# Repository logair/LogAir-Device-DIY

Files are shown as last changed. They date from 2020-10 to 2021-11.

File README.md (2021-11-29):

# Hardware docs for the DIY LogAir device

- Schematics
- PCB
- BoM
- Arduino code

The hardware as it is streams, once per second, the following data through BLE and to the uSD card:
Latitude, Longitude, Altitude, Speed, Heading, Temperature, Relative Humidity, Atmospheric Pressure, PM1, PM2.5, PM4, PM10

The Arduino-compatible MCU is a Bluepill, a generic implementation of the STM32F103. The chip is flashed with a code compiled with the Arduino IDE and the following libraries: NeoGPS, PMS Library, BME280, SdFat.

The data transmissio nprotocol is extensible to allow implementation of different sensors.

# How To

## Assemble
<details>
  <summary>Click to expand for instructions!</summary>
  
  ### Material

- LogAir PCB
- Bluepill + connectors
- BME280 + connector
- uSD module
- BLE module
- PMS7003 + connector
- DC step-up
- Charger module
- GPS module

- Soldering iron + tin
- double-sided tape + jelly tape if available
- cutting pliers
- flat pliers
  
  ### Instructions

0. A very first step should be to try and upload code to the Bluepill. This is before the rest as it happened that the chips could not be programmed, and realizing that after all that work is not ideal. Upload a bootloader, a blink code, and there you go.

1. Solder the Bluepill connectors. Use the holes in the PCB as a guide for alignment. The G (GND, ground) pins are harder to solder, because of the copper mass involved.
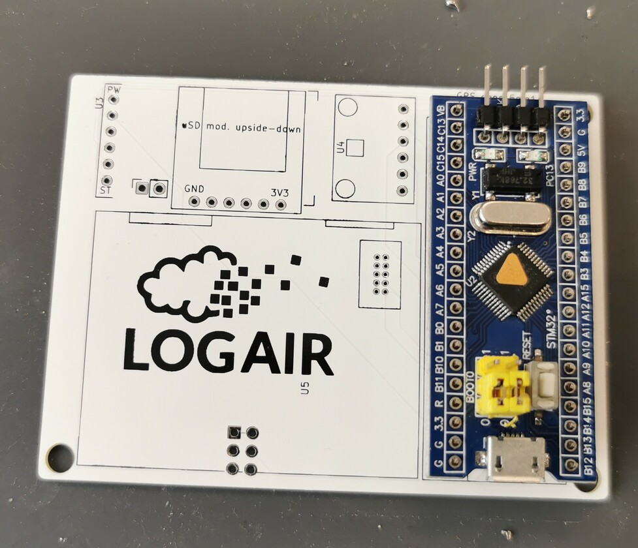
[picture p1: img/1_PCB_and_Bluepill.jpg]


2. Solder the assembled Bluepill to the PCB. Pay attention to the orientation.
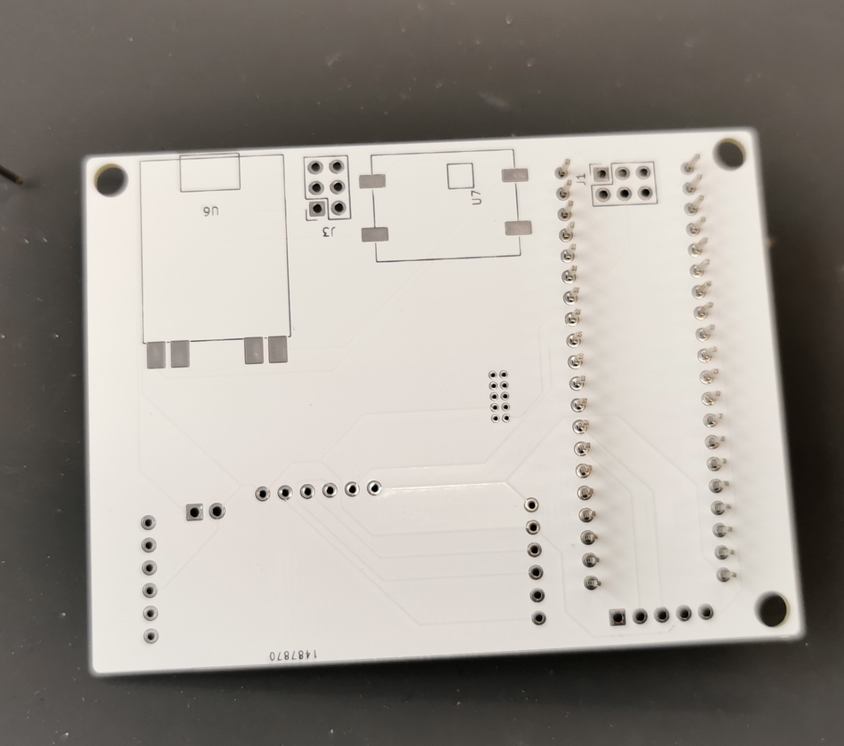
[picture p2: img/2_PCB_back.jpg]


3. Prepare the BME280 (solder the connectors), the BLE module (straighten the pins with a flat plier), and the uSD module
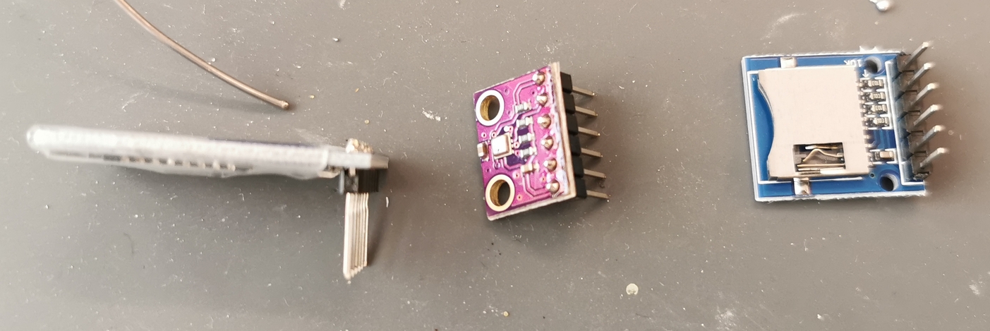
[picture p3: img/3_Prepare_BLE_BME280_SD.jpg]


4. Place the BLE, BME, and uSD modules. Follow the picture, the BME280 (violet module) should be as far as possible from the PCB), with its pins barely sticking through on the other side.
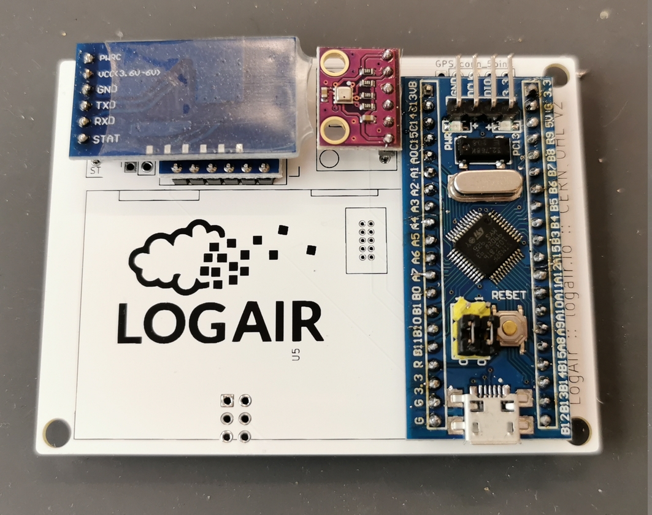
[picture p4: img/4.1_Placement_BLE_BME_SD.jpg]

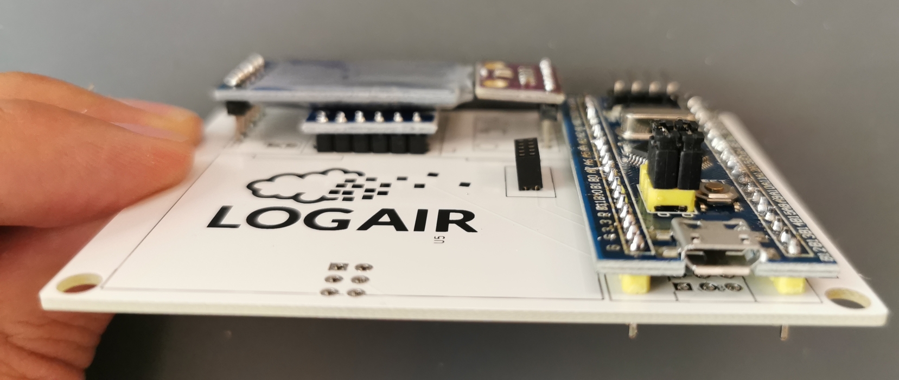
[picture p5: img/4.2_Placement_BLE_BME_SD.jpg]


5. Prepare the PCB for the power modules: put a thin layer of tin on the (blue) charger module pads, and a solder blob on one of the (red) step-up pads
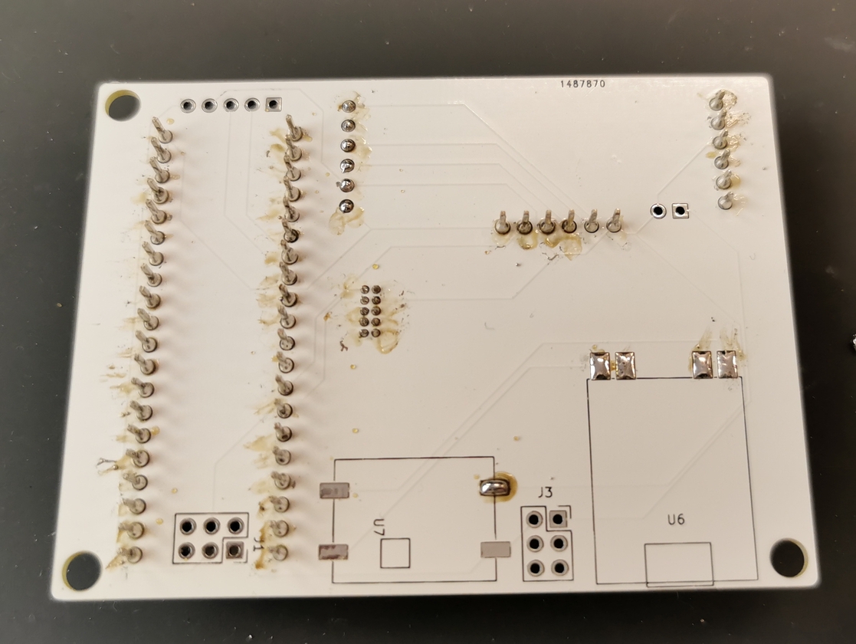
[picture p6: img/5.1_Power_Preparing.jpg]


6. Solder the charger module by putting it in place, and adding solder on the pads from the top. I count about 5 seconds of applying heat for the tin applied on step 5 to melt. Then solder the step-up module using the first pad to hold it in place. When you are done, check the conductivity between the pins of the two modules, and that between the pads of the charging module. The latter because the method used to solder can produce 'tin overflows'. 
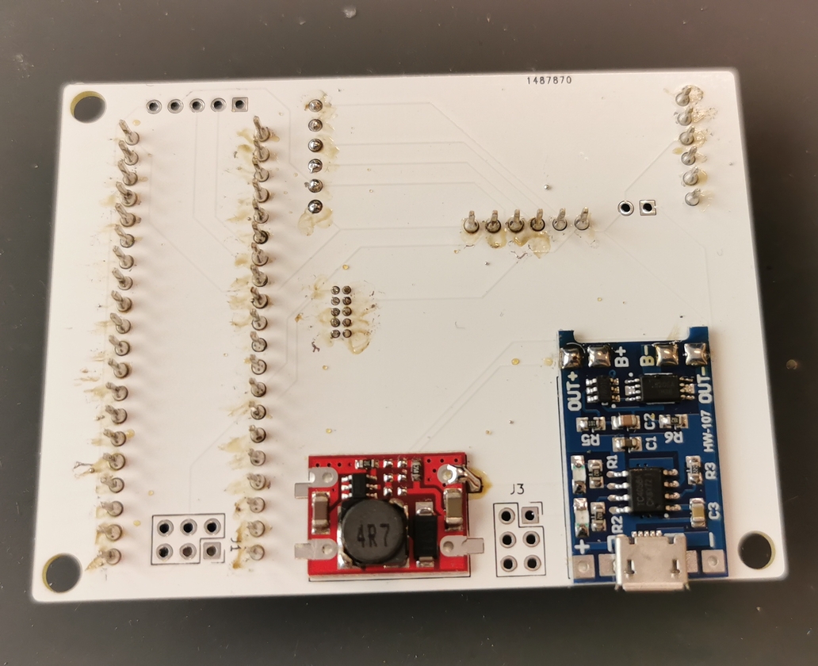
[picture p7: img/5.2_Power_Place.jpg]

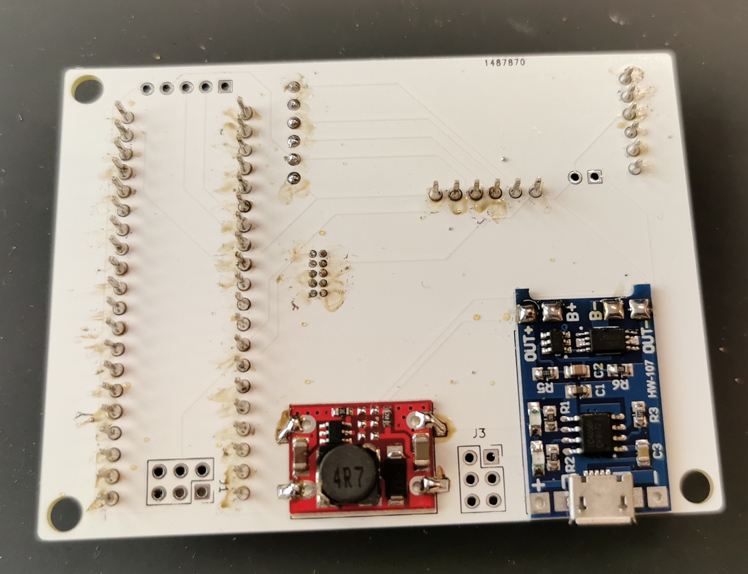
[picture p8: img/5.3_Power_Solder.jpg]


Then place and solder the switch. Here, try to apply a minimal amount of tin. As the other side of the pins will go against the PMS7003 which has a conductive casing, the pins should be cut or filed down, then taped over (two layers of normal, clear tape are enough)
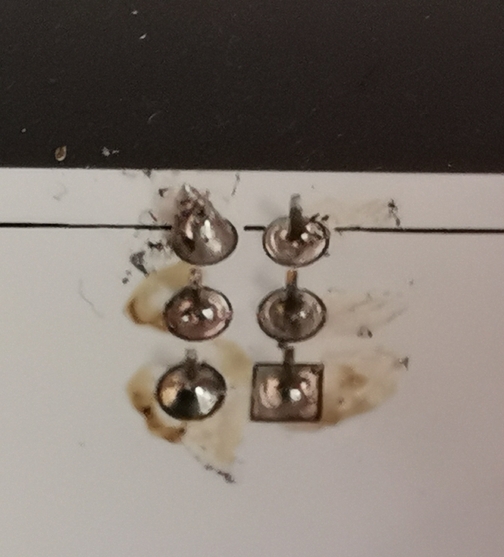
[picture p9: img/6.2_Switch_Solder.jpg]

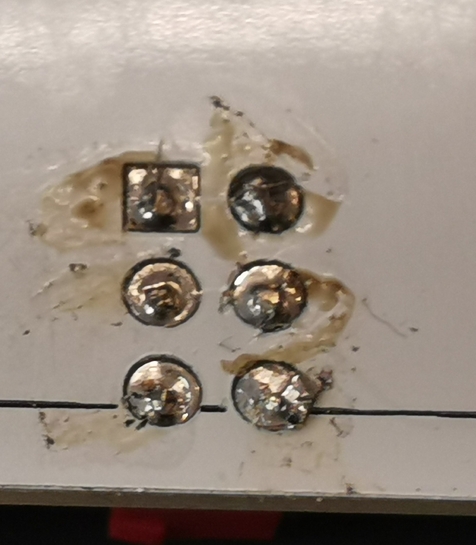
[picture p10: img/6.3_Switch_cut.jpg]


7. Bend lightly the SWD pins of the Bluepill to give room for soldering the GPS wires
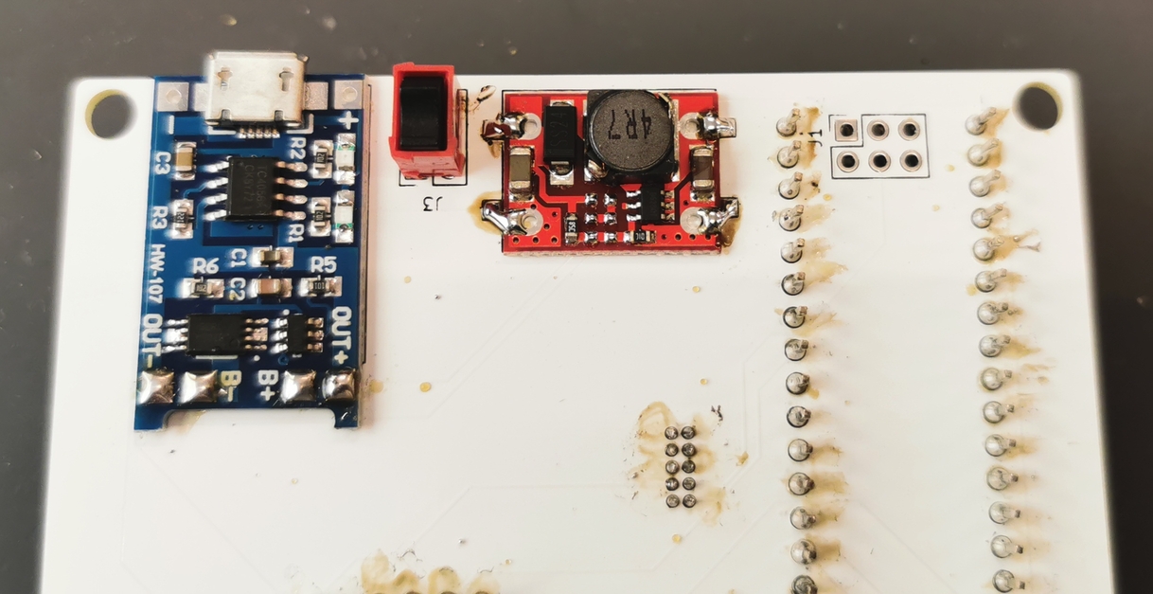
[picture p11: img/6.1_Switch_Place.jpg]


8. Solder the GPS wires. The order is the same as their order on the GPS-side plug, you can use the PCB markings (5V is red) and pictures to help you. The wires should not go over each other at any point for the order to be preserved.
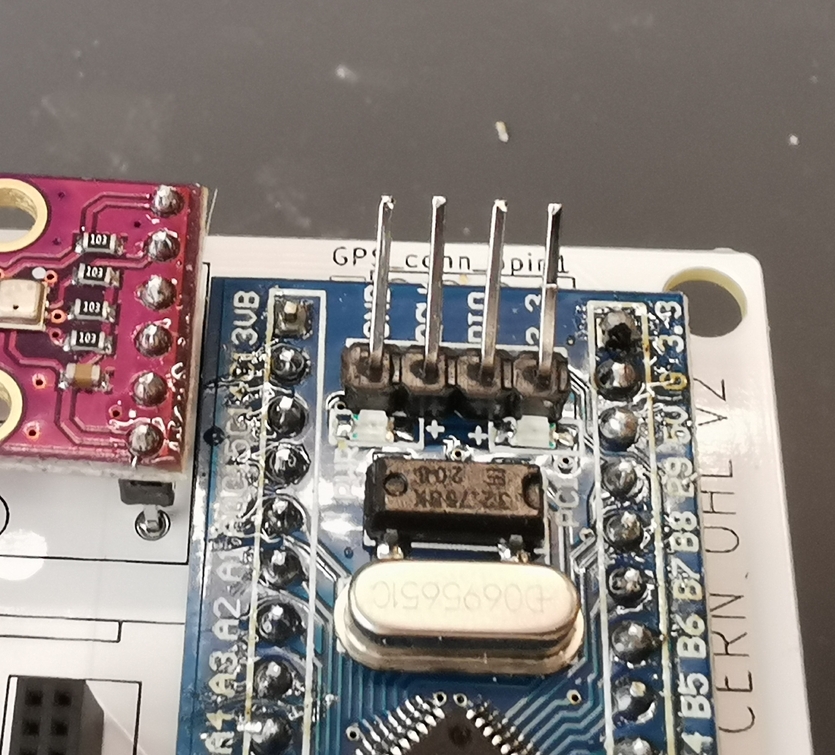
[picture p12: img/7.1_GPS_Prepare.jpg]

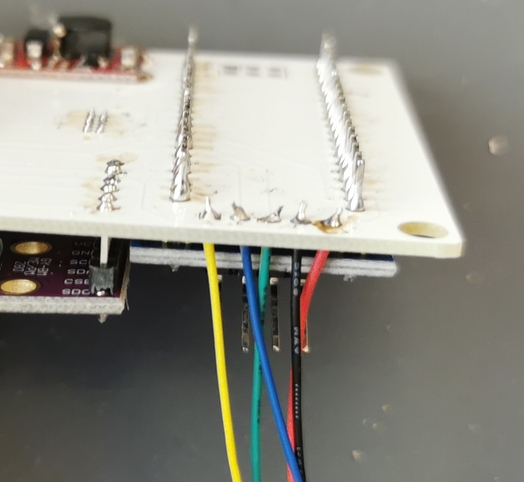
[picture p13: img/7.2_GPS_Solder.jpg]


9. Solder the connector for the PMS7003. As the width of the Bluepill vary a bit, it is safer to solder it lightly 'bent' away from the bluepill. To do that, solder the pins that are on the far side from the Bluepill first, then plug the PMS7003 in to see how thing fit. Then remove and solder the rest. 5-10 degrees should do.
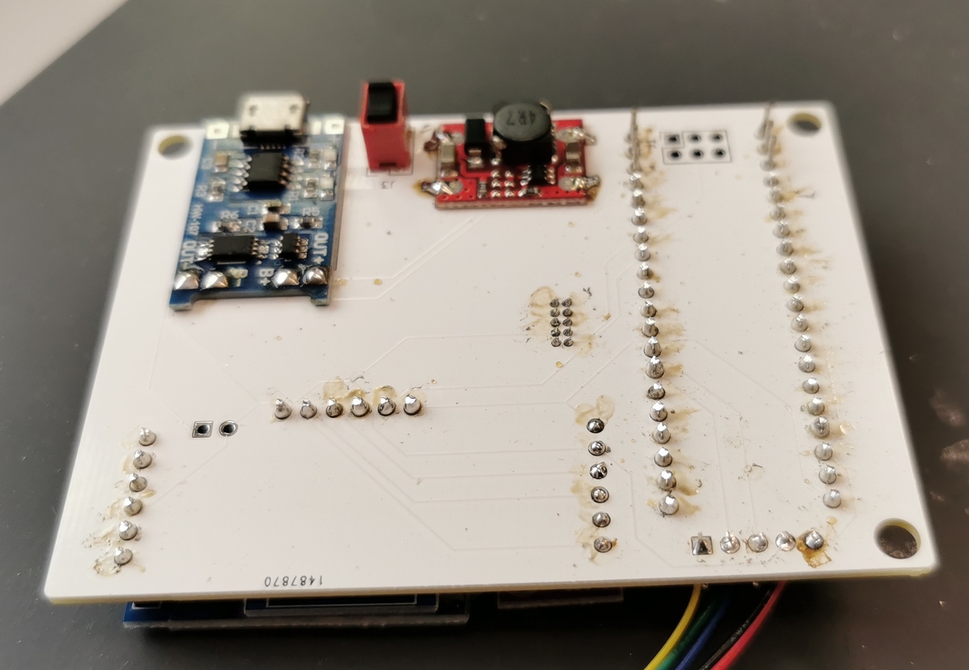
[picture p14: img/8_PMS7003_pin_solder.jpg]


10. For a smaller device, I cut most of the pins apparent on the back of the PCB to the top of the tin cone. Apply insulation on the pins, and this is important. I use a sticky, translucent, think tape I found on aliexpress. Any other ~1-2mm insulating material will easily do.
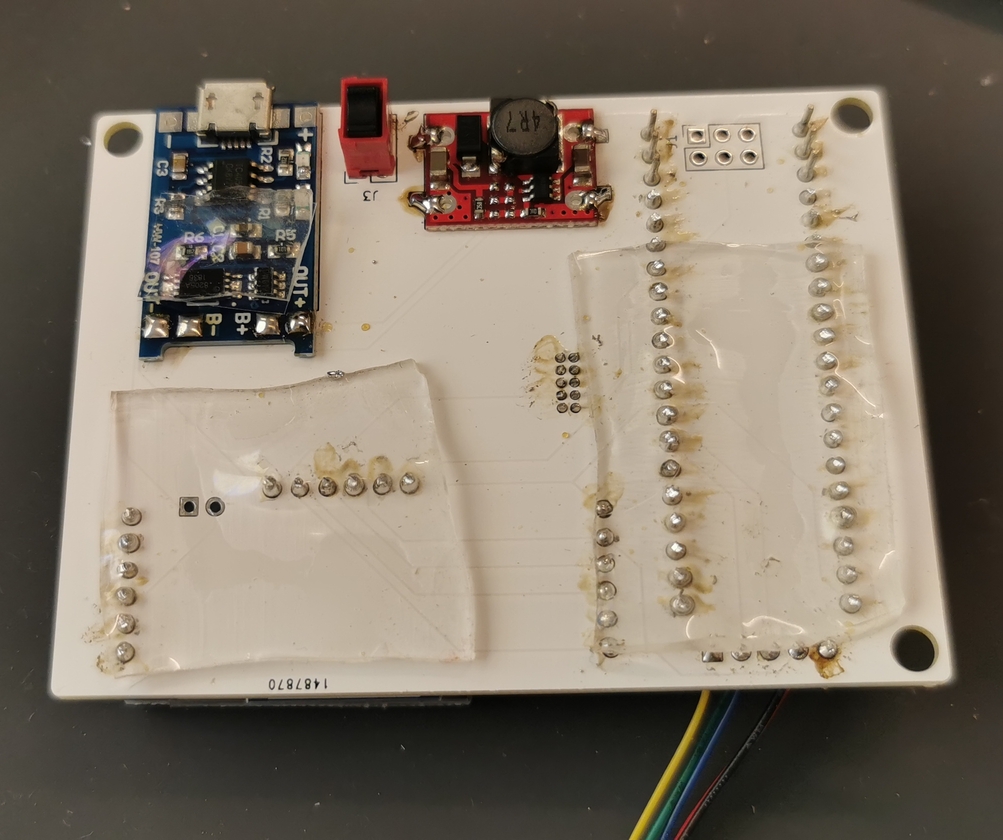
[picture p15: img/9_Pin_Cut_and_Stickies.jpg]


11. Solder the battery wires to the charger module pads
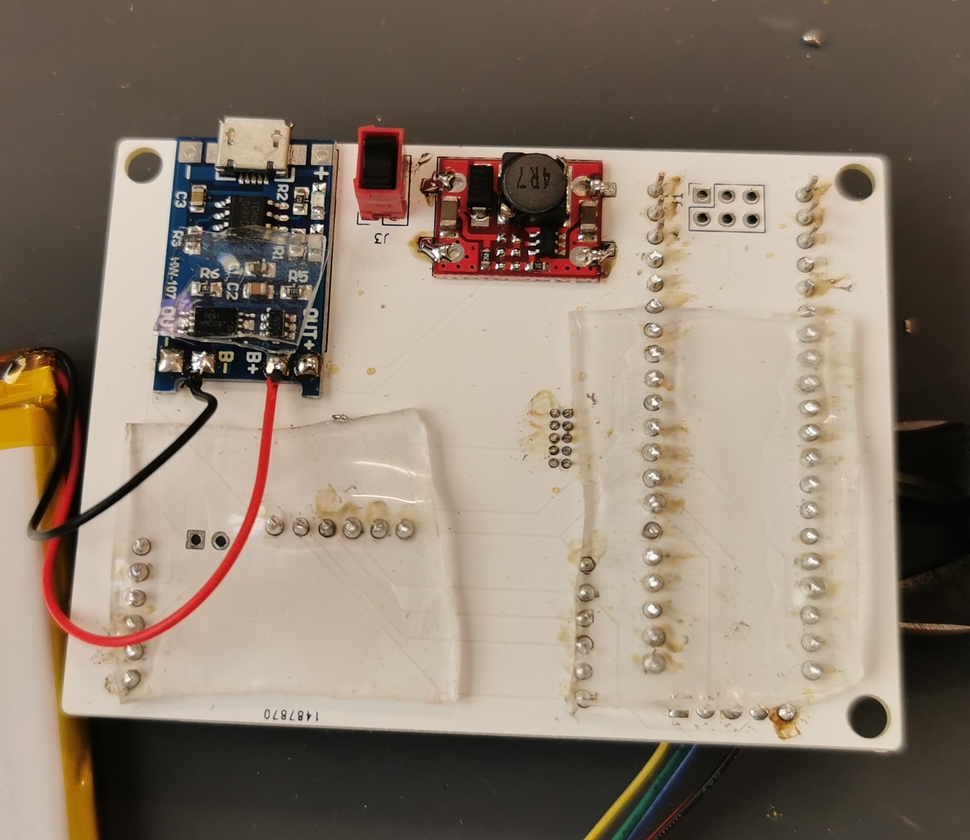
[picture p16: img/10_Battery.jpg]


12. Before finalizing the assembly, write down the PMS7003 serial number somewhere, to track device quality :)
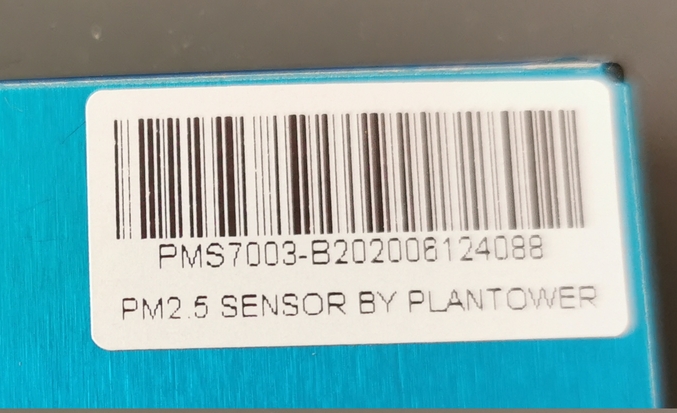
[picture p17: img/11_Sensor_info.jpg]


13. And it is done :)
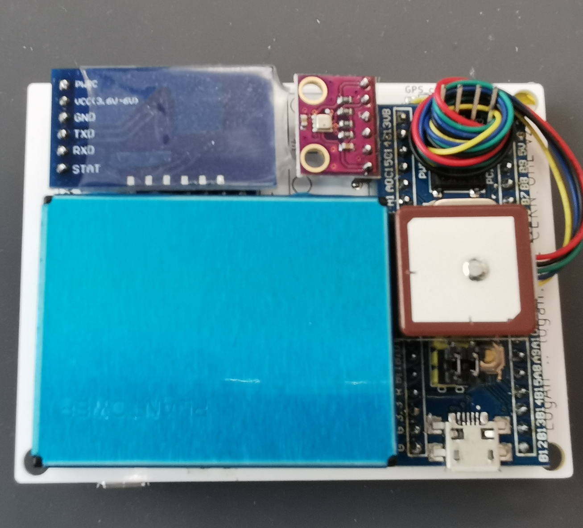
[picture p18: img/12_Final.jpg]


  </details>
  
## Program

<details>
  <summary>Click to expand for programming instructions!</summary>
  
### Pre-requisites
- A Bluepill with functional bootload (e.g. generic_boot20_pc13.bin from https://github.com/rogerclarkmelbourne/STM32duino-bootloader
- Install Arduino IDE
- Install board definition:File > Preferences > Additional Boards Manager URLs: add the following URL to the list (empty by default):
  `https://github.com/stm32duino/BoardManagerFiles/raw/main/package_stmicroelectronics_index.json`
- Tools > Board > Boards Manager > Search 'STM32' > Install 'STM32 MCU based boards'
    
<details>
<summary>For older instructions using unofficial stm32duino core</summary>
  
- Install board definition:File > Preferences > Additional Boards Manager URLs: add the following URL to the list (empty by default):
`http://dan.drown.org/stm32duino/package_STM32duino_index.json`
- Tools > Board > Boards Manager > Search 'STM32' > Install 'STM32F1xx/GD32F1xx boards'
- Once done, close the Board Manager and Select the Board: Tools > Board > STM32F1 Boards (Arduino_STM32) > Maple mini
  
NO NEED TO FOLLOW THE CONFIGURE SECTION BELOW.
    
</details>
  
### Configure
  - Select the proper board:
  `Tools > Boards > STM32 Boards (selected from submenu) > Generic STM32F1 series`
  - Enable configurations we need:
    - `Tools > U(S)ART Support > Enabled (Generic 'Serial')`
    - `Tools > USB Support > CDC (Generic Serial supersedes U(S)ART)`
    - `Tools > Upload Method > Maple DFU Bootloader 2.0`

### Libraries
Install the following libraries from the Library Manager
Tools > Manage Libraries... 

- NeoGPS: Install, and replace the contents of `$HOME/Arduino/libraries/NeoGPS/src/GPSport.h` by:
```
#ifndef GPSport_h
#define GPSport_h

#define gpsPort Serial2
#define GPS_PORT_NAME "Serial2"
#define DEBUG_PORT Serial

#endif
```
- BME280 by Tyler Glenn
- PMS Library by Mariusz Kacki
  
## Connect, compile and upload
Let us now try and upload a quick code to test if all works...

- Open the Blink example, and add `#define LED_BUILTIN PC13` at the very beginning
- Select the Port: Tools > Port > ... (depends on your OS)
- Press the Compile and Upload arrow....

If the upload does not go through, this might be because the board cannot auto-reset with your computer.
To upload, you will need to manually reset by pressing the button you can see near where the GPS chip is stuck just before pressing the Compile arrow. It takes a bit of trial and error and some OS's need it while some others don't.

## Upload the LogAir code
Download the code from the repository, and follow the same process as above.

## Connect
UART parameters to connect to the serial monitor are the ones set in the code. The default is 112500, but 9600 was previously used.

## Troubleshoot

### Board appears in dmesg, but not in lsusb 
You might need to create a udev rules file
`/etc/udev/rules.d/45-bluepill.rules`
```
ATTRS{idVendor}=="1eaf", ATTRS{idProduct}=="0004", MODE="0666" SYMLINK+="maple", ENV{ID_MM_DEVICE_IGNORE}="1"
ATTRS{idVendor}=="1eaf", ATTRS{idProduct}=="0003", MODE="0666" SYMLINK+="maple", ENV{ID_MM_DEVICE_IGNORE}="1"
```
  </details>
  
## Use

<details>
  <summary>Click to expand for usage instructions!</summary>
  
### Turning ON / OFF
The switch onthe back of the device allows to turn the device on and off.

The red or green blinking light shows when the device is writing on the SD card. When the LED is ON, the device should not be turned OFF as it might corrupt the card.

### Blinking LEDs

The modules we use include LEDs of varying colors. Here are some useful informations you can get from them:

- Bluetooth LED (green or red), left side of the device: This LED is blinking if no phone is connected to the device, and stays on when a connection is active.
- GPS LED (blue and red):
  - The red LED shows the module is powered, and should always be on when the device runs. 
  - The blue LED is blinking when the module receives signals strong enough to get a 'fix', or know its position. This is important if you rely on the SD card only to record the measurements, i.e. if you're not using a smartphone to send your data to the server.
- Device LEDs:
  - Left LED: red or green, signals the controller receives power. Should always be ON when the device is turned on.
  - Right LED: red or green, currently parametered to signal the device is writing to the SD card and should not be powered off. You can turn the device OFF when the LED is OFF.

### With the LogAir APP
Follow the instructions on our video tutorial.

### Stand-alone
The LogAir device records its measurements on the micro-SD card, which can be extracted and imported into a spreadsheet or GIS program.

The limitation in this mode is that the device can only rely on its own GPS module for time and position. This means that, before a valid GPS signal is acquired, the measurements on the SD card will not list any time or position. 

The signal depends on your location, the time of the day, if there are obstacles between the device and the sky, etc. Indoor measurements are often difficult, but windowsills sometimes give good results.

We are trying to find a way to give the current time to the device by using a program on the computer, or preparing it on the SD card, but there is no easy solution there... See ToDos, input welcome :)

</details>

# ToDo

Here are several items that are planned, currently developed, or on hold pending contributions. If you are interested in any of them be it for giving a helping hand or advices, please get in touch :)
  
## Hardware

These items focus on the device conception, including electronics, casing, production, etc.

<details>
  <summary>Click to expand for Hardware development tasks!</summary>
  
- Disconnect PC14 and PC15 for RTC reliability
- Better power supply, as this one just charges and discharges blindly.
- Integrate the components on a printed circuit board
- Replace the BLE module with an ESP32 (the STM32 might have to stay, as ESP32 are more limited, e.g., available UARTs)
- Make a similar MVP with SPS30 & SHT3x
- Add a LoRa chip! See Clement's work
- ...

</details>

## Firmware

Firmware development focuses on the program that makes the device run. The brain within the machine :)

<details>
  <summary>Click to expand for Firmware development tasks!</summary>

- Provide a time base when no GPS signal is present, and no phone is connected
  - Implement RTC (there is an on-board crystal on the Bluepill).
  - Implement time input from serial (BLE and/or PC)
- Implement better data storage and upload 
  - Log data with human-readable time as well as UNIX timestamp
  - Revamp buffering to limit uSD write operations
  - Revamp data storage on the SD card (textfile + DB?)
  - Implement deferred data upload for when uplink not continuously available
- Implement online GPS config: some changes to the embedded GPS FW are sometimes necessary for best operation
  - Get and store almanach/ephemeris on uSD card! This would really help with no-phone collection
  - Other generic config, constellations, accuracy requirements, etc.
- Implement component recognition: find out which sensors are used from their output stream (starting with PM sensor)
- Add interrupts everywhere?
- ...

</details>

## APP

Here, developmetn of our application that helps collect and send data from the device to the servers, and get it back in forms of maps, messages, etc. Our UI sucks? Contribute a better one ;)

<details>
  <summary>Click to expand for APP development tasks!</summary>
  
- All 
  - Implement API key for upload/download

- Android version
  - APP should check at startup that GPS is enabled (and available in background if knowable) and prompt if not. 
  - Make it simpler: no settings, sending all packets stored every 10sec, etc
  - Auto-connect: priority to previously connected devices, then to '.*logair.*', etc
  - Map should be loaded at startup, not only when map tab is opened
  - ...

- iOS version
  - Make one :x Nicos is on it!
  - ...

</details>

## Backend

All the work that helps gather the data, safekeep it, develop ways to use it, share it, etc. DBs, services, APIs and the like. Put your hoodie on and hack away!

<details>
  <summary>Click to expand for Backend development tasks!</summary>
  
  - Implement API key for upload/download
  - ...

</details>

## Data

All the work that develop ways to analyse, understand and use the data. Algorithms, GIS, dashboards etc.

 <details>
  <summary>Click to expand for Data visualisation and Data science tasks!</summary>
  
  - Make a dashboard! 
  - Build a QGIS server that works fast enough
  - Find missing data points in the contributions, and signal them for collection
  - Find periods in the signal, and exploit them
  - Build a better pipeline for extraction and analysis

</details>

# Upcoming

- Arduino library configs
- ToDo list updates
- Assembly instructions (video?)

Licensed under [CERN OHL v.1.2 or later](https://ohwr.org/project/cernohl/wikis/home)

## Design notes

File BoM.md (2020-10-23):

|Part | Cost (USD)  | Data Sheet |
|---|---|---|
|PMS 7003  |$13.00 |http://www.aqmd.gov/docs/default-source/aq-spec/resources-page/plantower-pms5003-manual_v2-3.pdf|
|BME280 SPI |$3.00 |https://cdn-shop.adafruit.com/datasheets/BST-BME280_DS001-10.pdf |
|GG1802 gps |$10.00 |http://www.stotoncn.com/gnssmodule/showproduct.php?lang=en&id=63 |
|HM-10 compatible bluetooth |$4.00 | https://www.iot-experiments.com/jdy-08/ |
|Bluepill |$2.00 |https://www.techshopbd.com/uploads/product_document/STM32bluepillarduinoguide(1).pdf |
|Battery 3000 mAh + Battery charger + DC converter  |$7.00 | |
|Extras: switches, cables, case |$3.00 | |
|PCB LogAir| 2.00$ | |

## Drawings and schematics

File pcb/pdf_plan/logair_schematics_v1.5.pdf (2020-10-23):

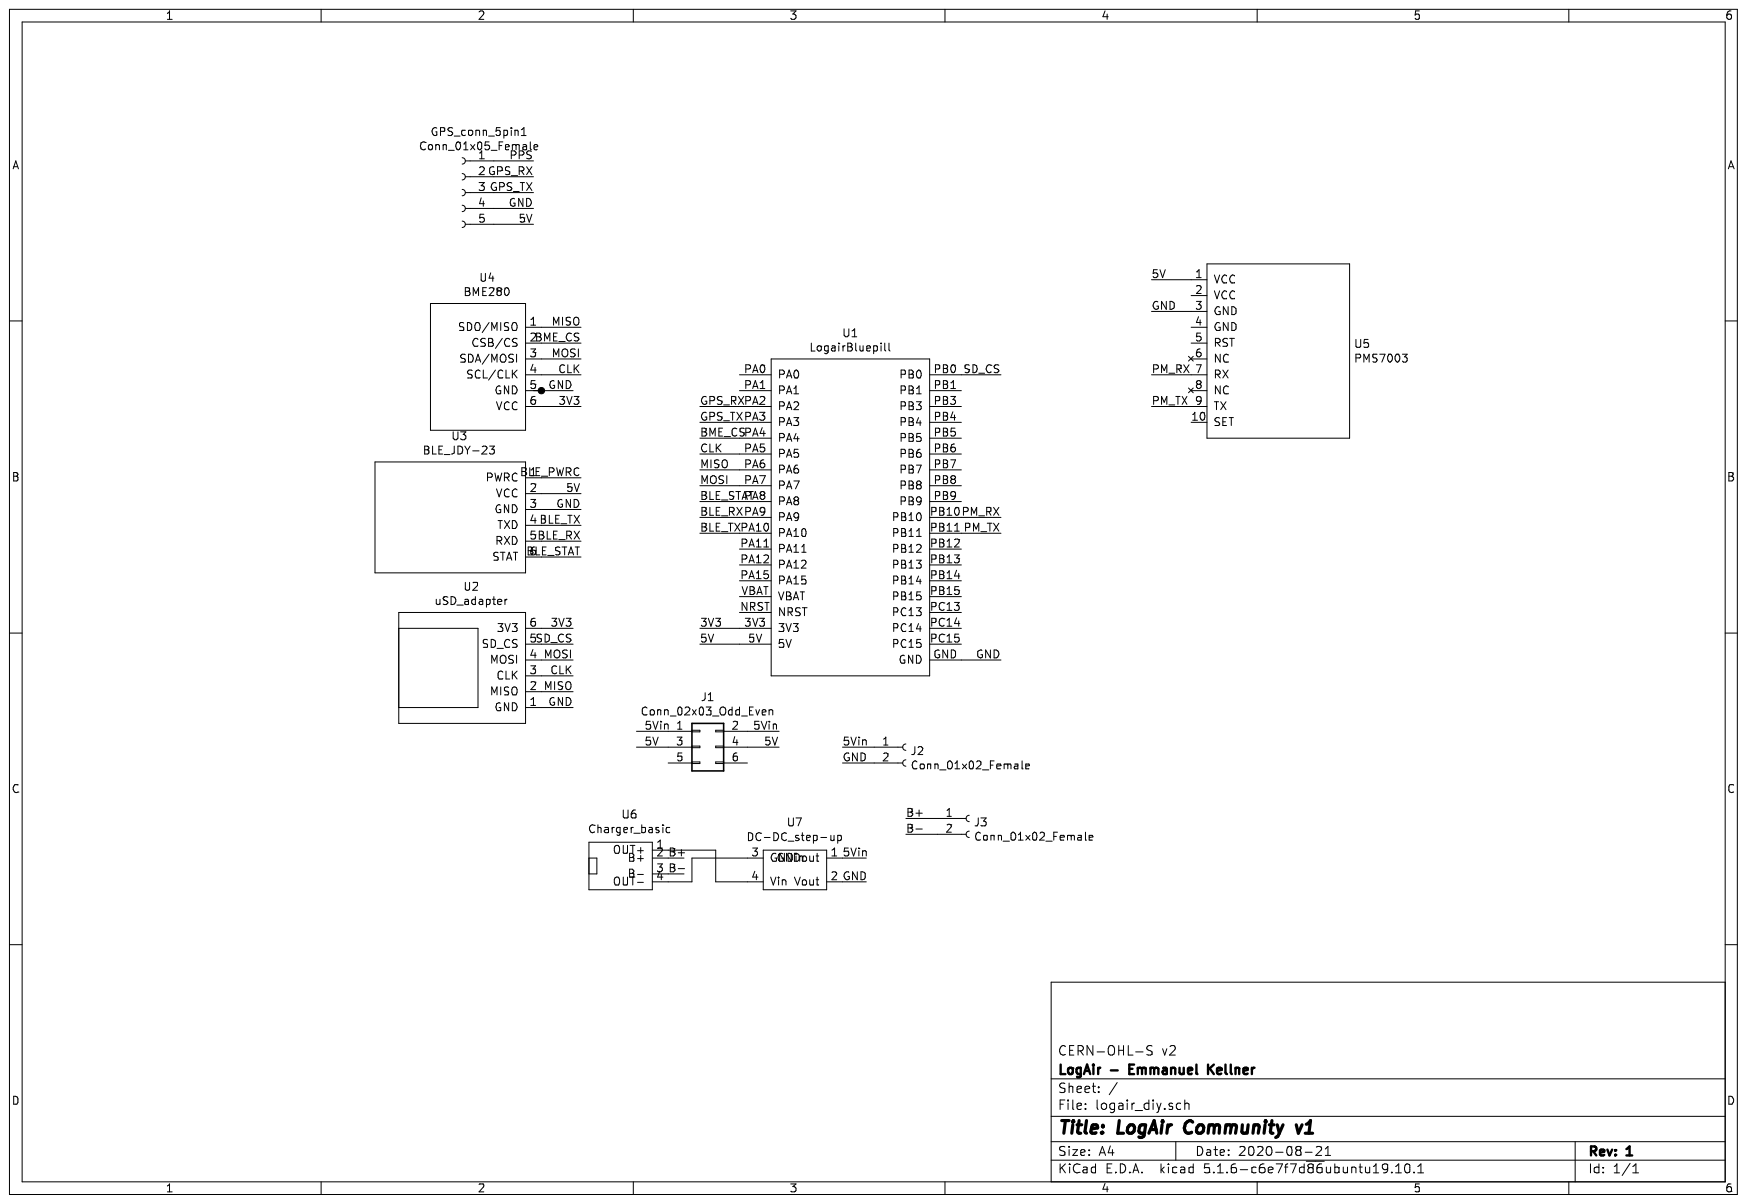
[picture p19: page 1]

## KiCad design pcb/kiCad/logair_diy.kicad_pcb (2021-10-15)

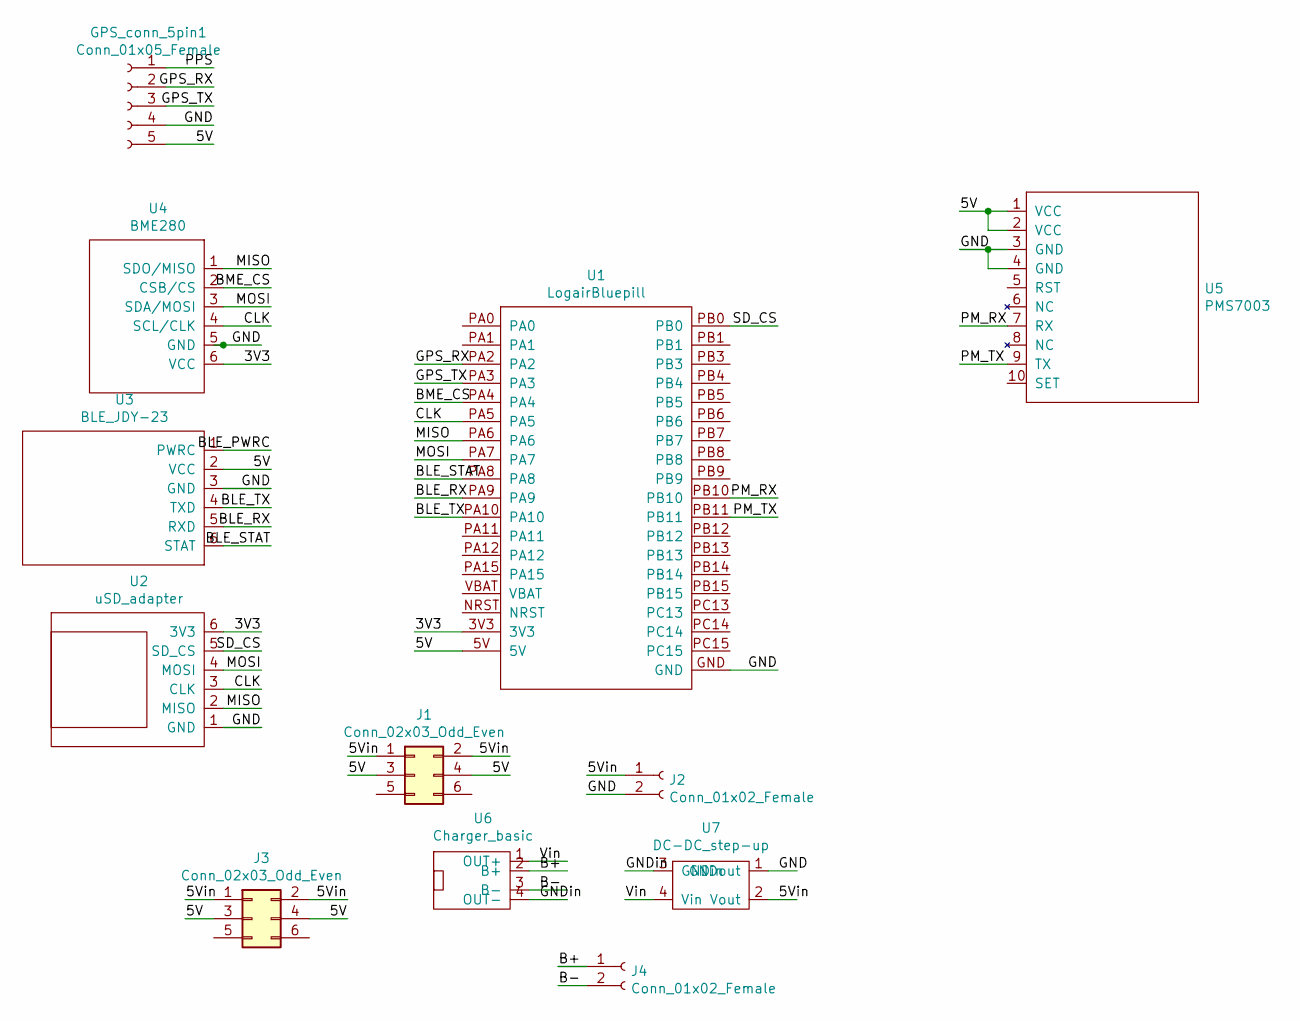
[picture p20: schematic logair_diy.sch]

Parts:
GPS_conn_5pin1: Conn_01x05_Female; PinHeader_1x05_P2.54mm_Vertical
J1: Conn_02x03_Odd_Even; PinHeader_2x03_P2.54mm_Vertical
J2, J4: Conn_01x02_Female; PinSocket_1x02_P2.54mm_Vertical
J3: Conn_02x03_Odd_Even; Logair_switch_2
U1: LogairBluepill
U2: uSD_adapter
U3: BLE_JDY-23; BLE_JDY-23_vert_unfold
U4: BME280; BME280_SPI
U5: PMS7003; PMS7003_10pin
U6: Charger_basic
U7: DC-DC_step-up; DC-DC step-up

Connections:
/3V3: U1.3V3, U2.6 (3V3), U4.6 (VCC)
/5V: GPS_conn_5pin1.5, J1.3, J1.4, J3.3, J3.4, U1.5V, U3.2 (VCC), U5.1 (VCC), U5.2 (VCC)
/5Vin: J1.1, J1.2, J2.1, J3.1, J3.2, U7.2 (Vout)
/B+: J4.1, U6.2 (B+)
/B-: J4.2, U6.3 (B-)
/BLE_PWRC: U3.1 (PWRC)
/BLE_RX: U1.PA9, U3.5 (RXD)
/BLE_STAT: U1.PA8, U3.6 (STAT)
/BLE_TX: U1.PA10, U3.4 (TXD)
/BME_CS: U1.PA4, U4.2 (CSB/CS)
/CLK: U1.PA5, U2.3 (CLK), U4.4 (SCL/CLK)
/GND: GPS_conn_5pin1.4, J2.2, U1.GND, U2.1 (GND), U3.3 (GND), U4.5 (GND), U5.3 (GND), U5.4 (GND), U7.1 (GNDout)
/GNDin: U6.4 (OUT-), U7.3 (GNDin)
/GPS_RX: GPS_conn_5pin1.2, U1.PA2
/GPS_TX: GPS_conn_5pin1.3, U1.PA3
/MISO: U1.PA6, U2.2 (MISO), U4.1 (SDO/MISO)
/MOSI: U1.PA7, U2.4 (MOSI), U4.3 (SDA/MOSI)
/PM_RX: U1.PB10, U5.7 (RX)
/PM_TX: U1.PB11, U5.9 (TX)
/PPS: GPS_conn_5pin1.1
/SD_CS: U1.PB0, U2.5 (SD_CS)
/Vin: U6.1 (OUT+), U7.4 (Vin)

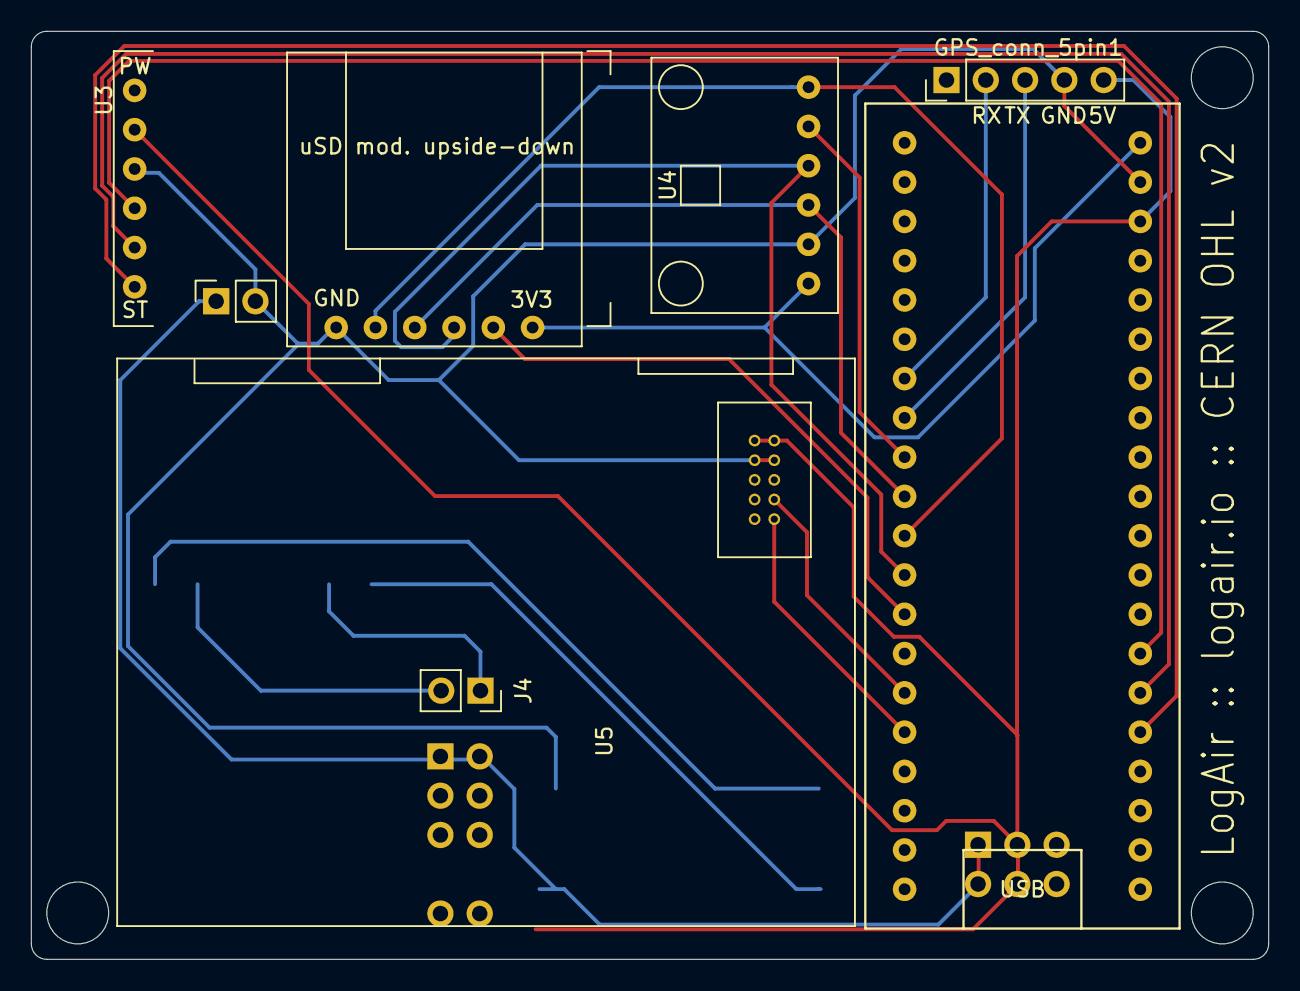
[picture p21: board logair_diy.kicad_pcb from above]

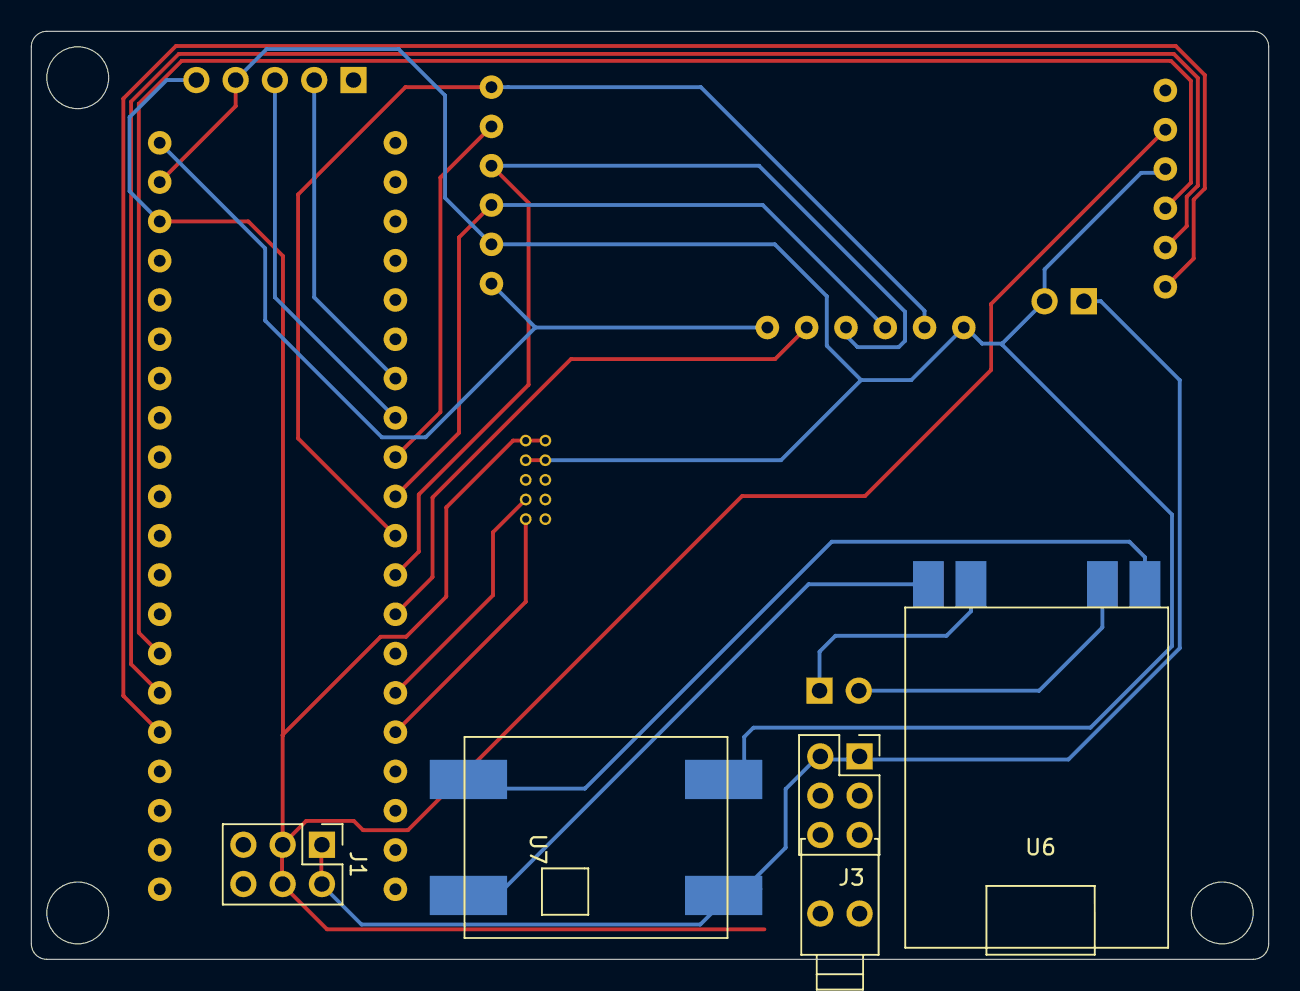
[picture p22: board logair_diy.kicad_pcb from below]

Board: 2 copper layers, 80.0 x 60.0 mm, 12 parts (4 on the bottom side), 20 nets.

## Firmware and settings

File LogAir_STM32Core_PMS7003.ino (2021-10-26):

//  License:
//    Copyright (C) 2017-2021, Emmanuel Kellner
//
//    This file is part of LogAir
//
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

#include <inttypes.h>
#include <math.h>
#include <string.h>
#include <stdio.h>

#include <SPI.h>
#include <BME280Spi.h>

#include <SD.h>
#include <SDConfigFile.h>

#include <NMEAGPS.h>
#include <GPSport.h> // choose the GPS module serial port
#include <Streamers.h> // common set of printing and formatting routines for GPS data in csv, printed to debug output device

#include "PMS.h"

// Bluepill to PC SERIAL BAUDRATE
#define USB_SERIAL 115200

// SPI device pin definition
#define DEVICE_PIN PA4

// LED pin and status definition
#define LED_BUILTIN PC13 // User LED pin definition
#define LED_OFF 1 
#define LED_ON 0

// Default config values, if logair.cfg not present on SD card
#define default_deviceID "LA-CF"
#define default_fwID "CC_0.7_proto"
#define default_pmID "PMS7003"
#define default_rhID "GY-BME280"
#define default_gpsID "ATGM336H"
#define default_rfID "JDY_023_gen"
#define default_bleName "logair"

// GPS config 
const char baud115200 [] PROGMEM = "PUBX,41,1,3,3,115200,0";

/*
HardwareSerial SerialX( RX, TX)
*/
//HardwareSerial Serial1(PB7,PB6);
HardwareSerial Serial2(PA3,PA2);
HardwareSerial Serial3(PB11,PB10);

int battery;


int connected = 0;
int header_step = 10;

const uint8_t SDChipSelect = PB0; // SD Chip Select pin



// HEADER
char header [128] =""; // header buffer
  
static NMEAGPS  gps; // parse received characters into gps.fix() data structure
static gps_fix  fix; // define set of GPS fix information. Will hold on to various pieces as received from RMC sentence


BME280Spi::Settings settings(
   DEVICE_PIN,
   BME280::OSR_X1, // Temperature
   BME280::OSR_X1, // Humidity
   BME280::OSR_X1, // Pressure
   BME280::Mode_Forced,
   BME280::StandbyTime_1000ms,
   BME280::Filter_Off,
   BME280::SpiEnable_False
   ); // Default : forced mode, standby time = 1000 ms, Oversampling = pressure ×1, temperature ×1, humidity ×1, filter off,

BME280Spi bme(settings);

PMS pms(Serial3);
PMS::DATA data;

int pm1, pm25, pm4, pm10;
int batt = 1 ; 
   
// The filename of the configuration file on the SD card
const char CONFIG_FILE[] = "logair.cfg";

// CONFIG
boolean didReadConfig;
char *deviceID;
char *fwID;
char *pmID;
char *rhID;
char *gpsID;
char *rfID;
char *bleName;

boolean readConfiguration() {
  const uint8_t CONFIG_LINE_LENGTH = 127;

  // The open configuration file.
  SDConfigFile cfg;

  // Open the configuration file.
  if (!cfg.begin(CONFIG_FILE, CONFIG_LINE_LENGTH)) {
    Serial.print("Failed to open configuration file: ");
    Serial.println(CONFIG_FILE);
    return false;
  }

  // Read each setting from the file.
  while (cfg.readNextSetting()) {

    if (cfg.nameIs("deviceID")){ deviceID = cfg.copyValue(); }
    else if (cfg.nameIs("fwID")){ fwID = cfg.copyValue(); }
    else if (cfg.nameIs("pmID")){ pmID = cfg.copyValue(); }
    else if (cfg.nameIs("rhID")){ rhID = cfg.copyValue(); }
    else if (cfg.nameIs("gpsID")){ gpsID = cfg.copyValue(); }
    else if (cfg.nameIs("rfID")){ rfID = cfg.copyValue(); }
    else if (cfg.nameIs("bleName")){ bleName = cfg.copyValue(); }
    else {}
    }
  
  // clean up
  cfg.end();

  return true;
}

// was const char*
void sendATCommand(char * command){

  Serial1.println(command);
  //wait some time
  delay(100);
  
  char reply[100];
  int i = 0;
  while (Serial1.available()) {
    reply[i] = Serial1.read();
    i += 1;
  }
  //end the string
  reply[i] = '\0';
  Serial.print(reply);
  Serial.println("Reply end");
}

// WORK FUNCTION, ALL TIME CONSUMiNG TASKS GO THERE
static void doSomeWork()
{


  char buffer [128] =""; // buffer
  
  char bufferSD [256] = ""; // buffer for SD writing
  
  sprintf(bufferSD, deviceID);
    
  if (fix.valid.location){
    
    uint32_t timestamp = (NeoGPS::clock_t) fix.dateTime;
    timestamp += 946684800; // convert from Y2K to UNIX Epoch
    
    sprintf(bufferSD, "%s,%" PRIu32 "", bufferSD, timestamp); // timestamp in seconds from EPOCC Y2K

    sprintf(buffer, "[%f,%f,%d,%.1f,%.1f", 
        fix.latitude(), fix.longitude(), (int) round(fix.altitude()), 
        fix.speed_kph(), fix.heading() );

    sprintf(bufferSD, "%s,%f,%f,%d,%.1f,%.1f", bufferSD, 
        fix.latitude(), fix.longitude(), (int) round(fix.altitude()), 
        fix.speed_kph(), fix.heading() );

  } else {
    sprintf(buffer, "[,,,,");
    sprintf(bufferSD, "%s,,,,", bufferSD);
    
  }
   
///////////////////////////////////////////////////////// BME280
  float temp(NAN), hum(NAN), pres(NAN);
  BME280::TempUnit tempUnit(BME280::TempUnit_Celsius);
  BME280::PresUnit presUnit(BME280::PresUnit_Pa);
  bme.read(pres, temp, hum, tempUnit, presUnit);

    int pres_i = round(pres);
    int temp_i=round(temp);
    int hum_i=round(hum);

///////////////////////////////////////////////////////// PMS7003
  if (pms.read(data)){
    // Check
    pm10 = data.PM_AE_UG_10_0 ;
    pm25 = data.PM_AE_UG_2_5 ;
  }

//  float pm25_corr, pm10_corr;
//  pm25_corr = pm25 / ( 1.0 + 0.48756*pow( ( hum / 100.0 ), 8.60068 ) );
//  pm10_corr = pm10 / ( 1.0 + 0.81559*pow( ( hum / 100.0 ), 5.83411 ) );


  sprintf(buffer, "%s,%d.%02d,%d.%02d,%d.%02d,,%d,,%d$", buffer, int(temp), int(temp*100)%100, int(hum), int(hum*100)%100, int(pres), int(pres*100)%100, pm25, pm10);
  sprintf(bufferSD, "%s,%d.%02d,%d.%02d,%d.%02d,,%d,,%d$", bufferSD, int(temp), int(temp*100)%100, int(hum), int(hum*100)%100, int(pres), int(pres*100)%100, pm25, pm10);

//  sprintf(buffer, "%s,%.1f,%.1f,%.1f,,%d,,%d$", buffer, temp, hum, pres, pm25, pm10);
//sprintf(bufferSD, "%s,%.1f,%.1f,%.1f,,%d,,%d$", bufferSD, temp, hum, pres, pm25, pm10);

  digitalWrite(LED_BUILTIN,LED_ON);

  File logfile = SD.open("dust.txt", O_RDWR | O_APPEND);  // open logfile
  if (!logfile){                                          // if file doesn't exist
    logfile = SD.open("dust.txt", O_RDWR | O_CREAT);

    if(!logfile){                                         // Failed logfile opening/creation.
      if(Serial) Serial.println( F("Failed to open dust.txt") ); // Send message. ADD LED BLINKING
    }
      logfile.println("Header:DeviceId,FW_Version,pmSensorID,relhSensorID,gpsID,rfID");
      logfile.println("Body:Latitude,Longitude,Temperature[C],Relative_Humidity[%RH],Pressure[Pa],PM1,PM2.5,PM4,PM10");
  }

    logfile.println(bufferSD);
  logfile.close();


  digitalWrite(LED_BUILTIN,LED_OFF);
  
  Serial.println(buffer);
  Serial1.println(buffer);
} // doSomeWork


//---------- SETUP ------------//
void setup()
{

  pinMode(LED_BUILTIN, OUTPUT);
  pinMode(PA8, INPUT);
  Serial.begin( USB_SERIAL ); // USB Serial

  SPI.begin();
  bme.begin();
  
  SD.begin(SDChipSelect);

  // Configuration
  didReadConfig = false;

  // giving default value to variables
  deviceID = default_deviceID;
  fwID = default_fwID;
  pmID = default_pmID;
  rhID = default_rhID;
  gpsID = default_gpsID;
  rfID = default_rfID;
  bleName = default_bleName;  

  // Read our configuration from the SD card file.
  didReadConfig = readConfiguration();

  delay(1000);
  
  // Bluetooth config
  Serial1.begin(9600); // Bluetooth

  sendATCommand("AT+BAUD0");
  sendATCommand("AT+BAUD0");
  sendATCommand("AT+RST");
  sendATCommand("AT+RST");

  Serial1.flush();
  delay(100);
  Serial1.end();
  Serial1.begin(115200);

  char bleNameString[sizeof("AT+NAME") + sizeof(bleName)]; 
  sprintf(bleNameString, "AT+NAME%s", bleName);

// The JDY-023 sometimes ignores the first AT+NAME commands given to it. We make sure it will get them again.
  for(int i=0; i<3; i++){
    Serial1.println(bleNameString);
    delay(100);
  }


  // CONFIG GPS TO 115200 bauds
  gpsPort.begin(9600); // Serial2
  gps.send_P( &gpsPort, (const __FlashStringHelper *) baud115200 );
  gpsPort.flush();
  delay(100);
  gpsPort.end();
  gpsPort.begin( 115200 ); 

  // Begin PMS7003
  Serial3.begin( 9600 ); // PMS7003

  // HEADER: deviceID, fwVersion, pmID, rhID, gpsID, rfID (radiofreq, BLE,LoRa,WiFi)
  sprintf(header, "{%s,%s,%s,%s,%s,%s$", deviceID, fwID, pmID, rfID, gpsID, rfID );

  Serial.println("end setup");
  Serial.flush();
  Serial1.flush();
}


void loop()
{
  
  while (gps.available( gpsPort )) {
    fix = gps.read();
    doSomeWork();
    header_step ++;
    }


  if (pms.read(data)){
    // Check
    pm10 = data.PM_AE_UG_10_0 ;
    pm25 = data.PM_AE_UG_2_5 ;
  }

  if (header_step > 10){
    header_step = 0;

    Serial1.println(header);
    Serial.println(header);

    if (digitalRead(PA8)){
      Serial.println("Connected");
    } else {
      Serial.println("Not Connected");
    }
  }
}

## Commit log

2020-08-27 Remove LoRa, add PCB
2020-10-23 Adding schematics and pcb
2021-10-15 add pcb file form kicad
    [logair_diy.drl, logair_diy.gbl, logair_diy.gbo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]
2021-10-21 Update README.md
    udev rules in case
2021-10-25 Adding assembly instruction pictures
2021-10-25 Adding assembly instructions
2021-10-26 Adding new STM32 Core

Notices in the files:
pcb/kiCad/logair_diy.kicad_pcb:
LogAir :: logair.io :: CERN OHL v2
